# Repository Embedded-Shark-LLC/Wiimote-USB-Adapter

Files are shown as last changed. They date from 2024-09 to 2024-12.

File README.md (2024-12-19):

# Wiimote-USB-Adapter
This is a Wiimote adapter to wirelessly connect remotes for Dolphin or other emulators through a USB-C connection to a computer.

Includes support for sensor bar USB passthrough (power only) or external infrared LEDs to act as a standalone sensor bar.

## Features
- USB-C power/data input
- USB-A port for external sensor bars

## Concept
I wanted a way to connect Wiimotes to a computer without the overhead of third-party Bluetooth adapters.  This uses the OEM Wiimote Bluetooth module, so there is minimal latency and no weird syncing issues.

## Planned Features
- Enclosure with support for integrated IR LEDs to act as a standalone sensor bar

## PCB Renders
|PCB Front|PCB Back|
|---|---|
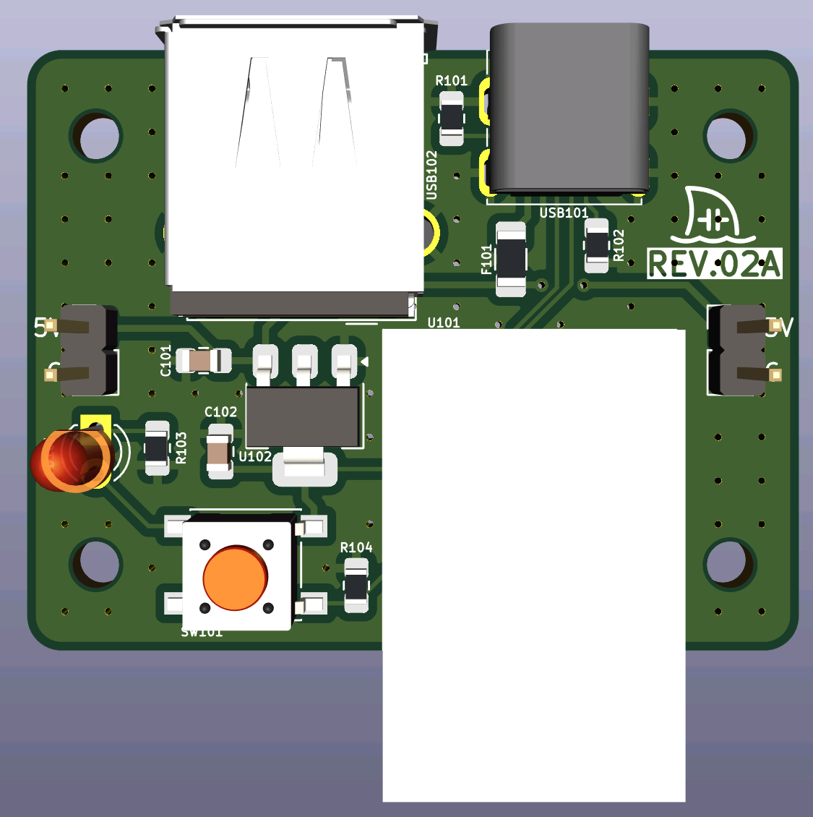
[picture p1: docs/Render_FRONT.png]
PCB front
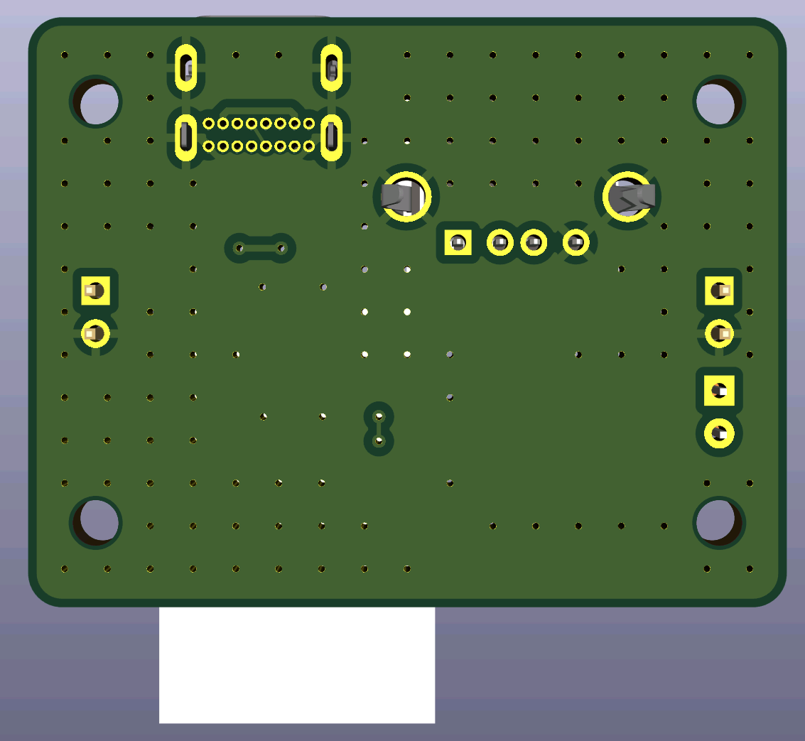
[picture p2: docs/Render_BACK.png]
PCB back
|||

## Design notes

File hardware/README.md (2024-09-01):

# Hardware

## Major components
| Description | Part Number | Manufacturer | Comments |
| --- | --- | --- | --- |
| Bluetooth module | J27H002 | Foxconn | OEM Wiimote BT module |
| Voltage regulator | LM1117MPX-3.3/NOPB | Texas Instruments | 3.3 V, 800 mA |
| USB A port | GSB12121RSKEU | Amphenol | THT, right angle |
| USB C port | GSB1C211110DS1HR | Amphenol | THT, USB 2.0, right angle |
| Sync button | PTS645SM50SMTR92 LFS  | C&K | SMD, vertical |

## Minor components
| Description | Part Number | Manufacturer | Comments |
| --- | --- | --- | --- |
| Resettable fuse | SMD1206B050TF/15 | YAGEO | 500 mA hold, 1 A trip, 15 V max |

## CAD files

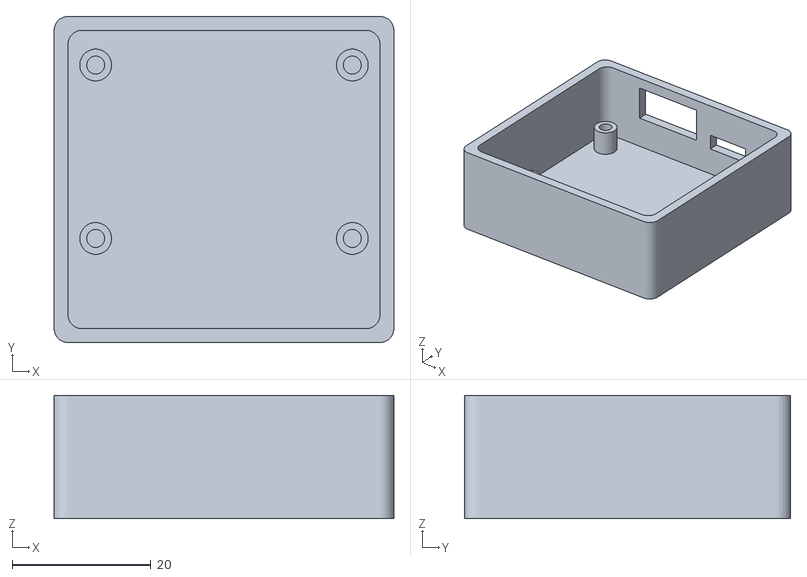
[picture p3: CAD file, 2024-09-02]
enclosure/Wiimote-USB-Adapter-Enclosure-Body.stl
49.0 x 47.0 x 17.8

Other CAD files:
enclosure/Wiimote-USB-Adapter-Enclosure.FCStd

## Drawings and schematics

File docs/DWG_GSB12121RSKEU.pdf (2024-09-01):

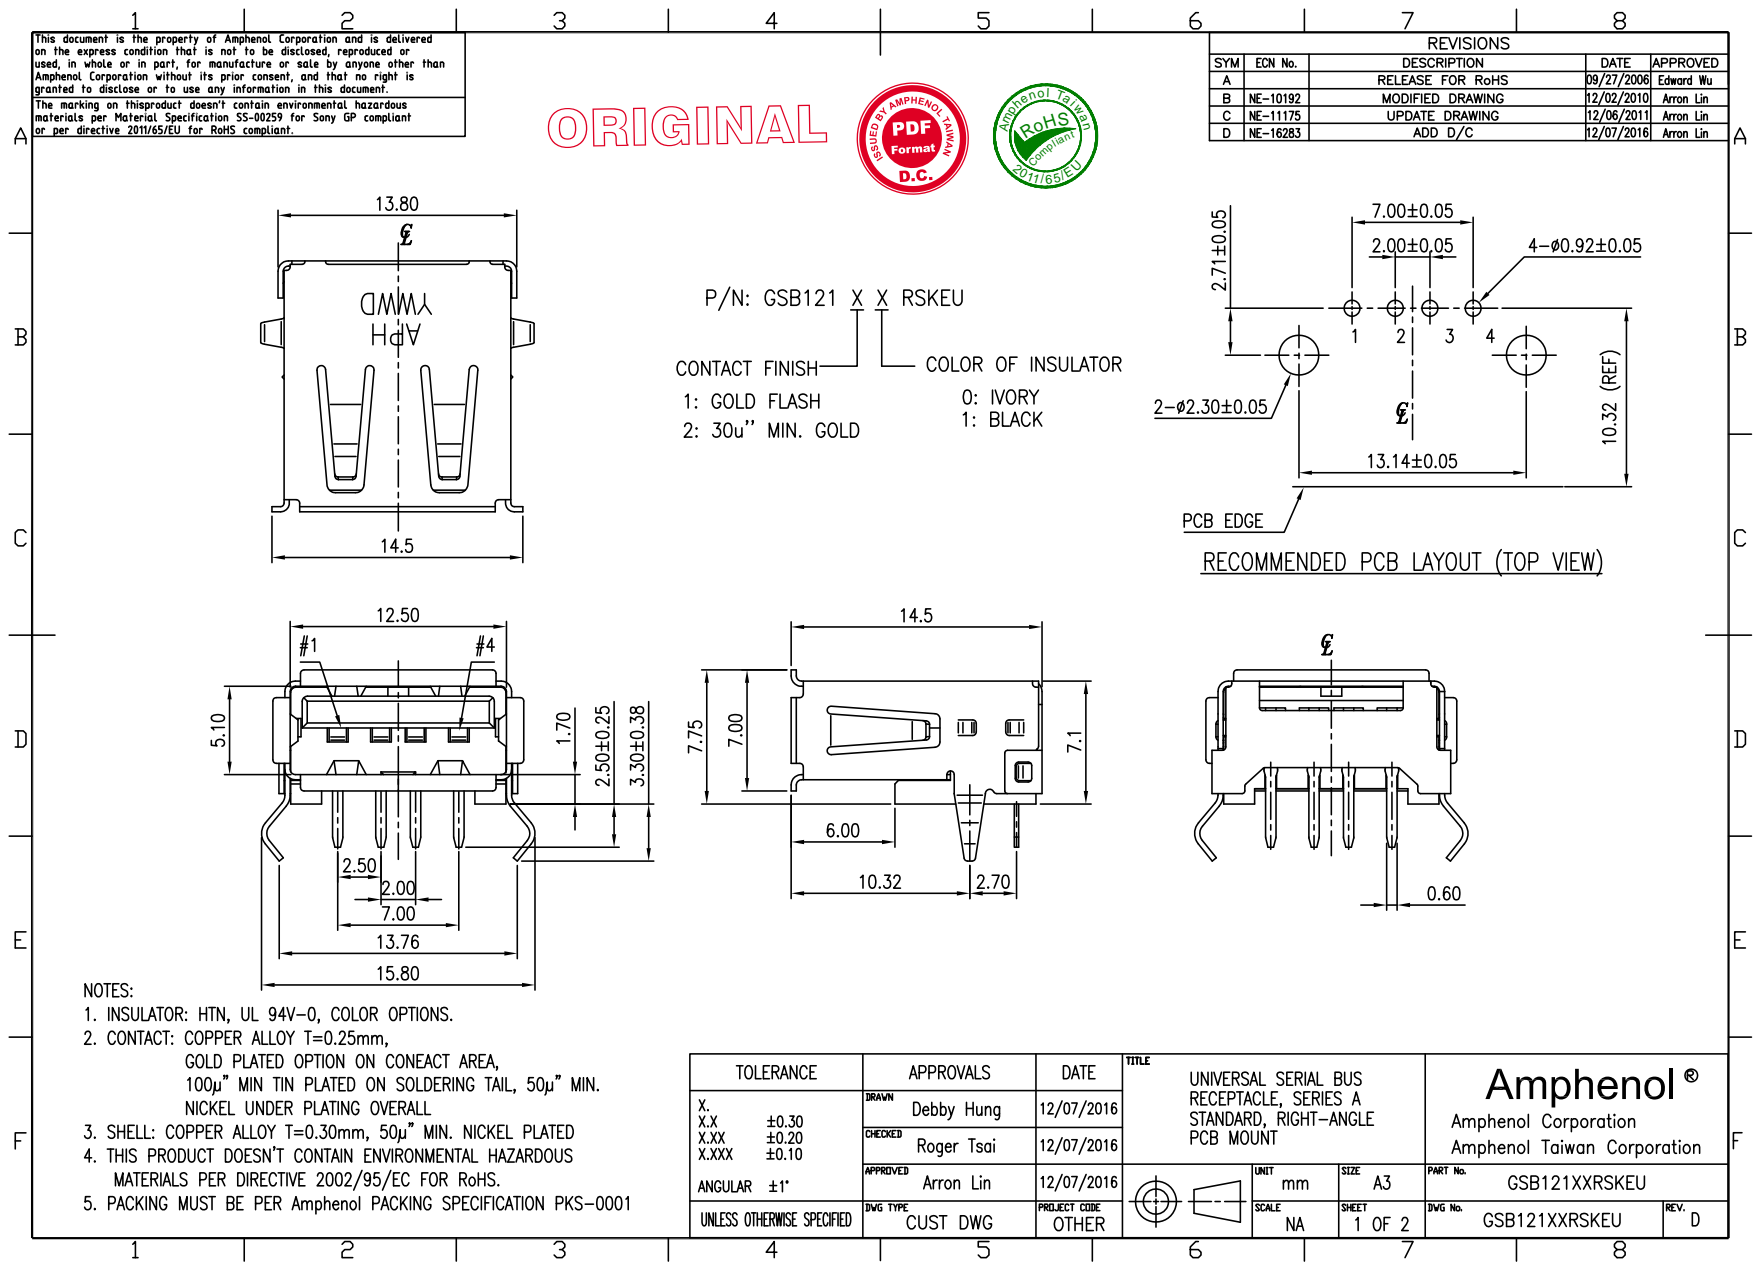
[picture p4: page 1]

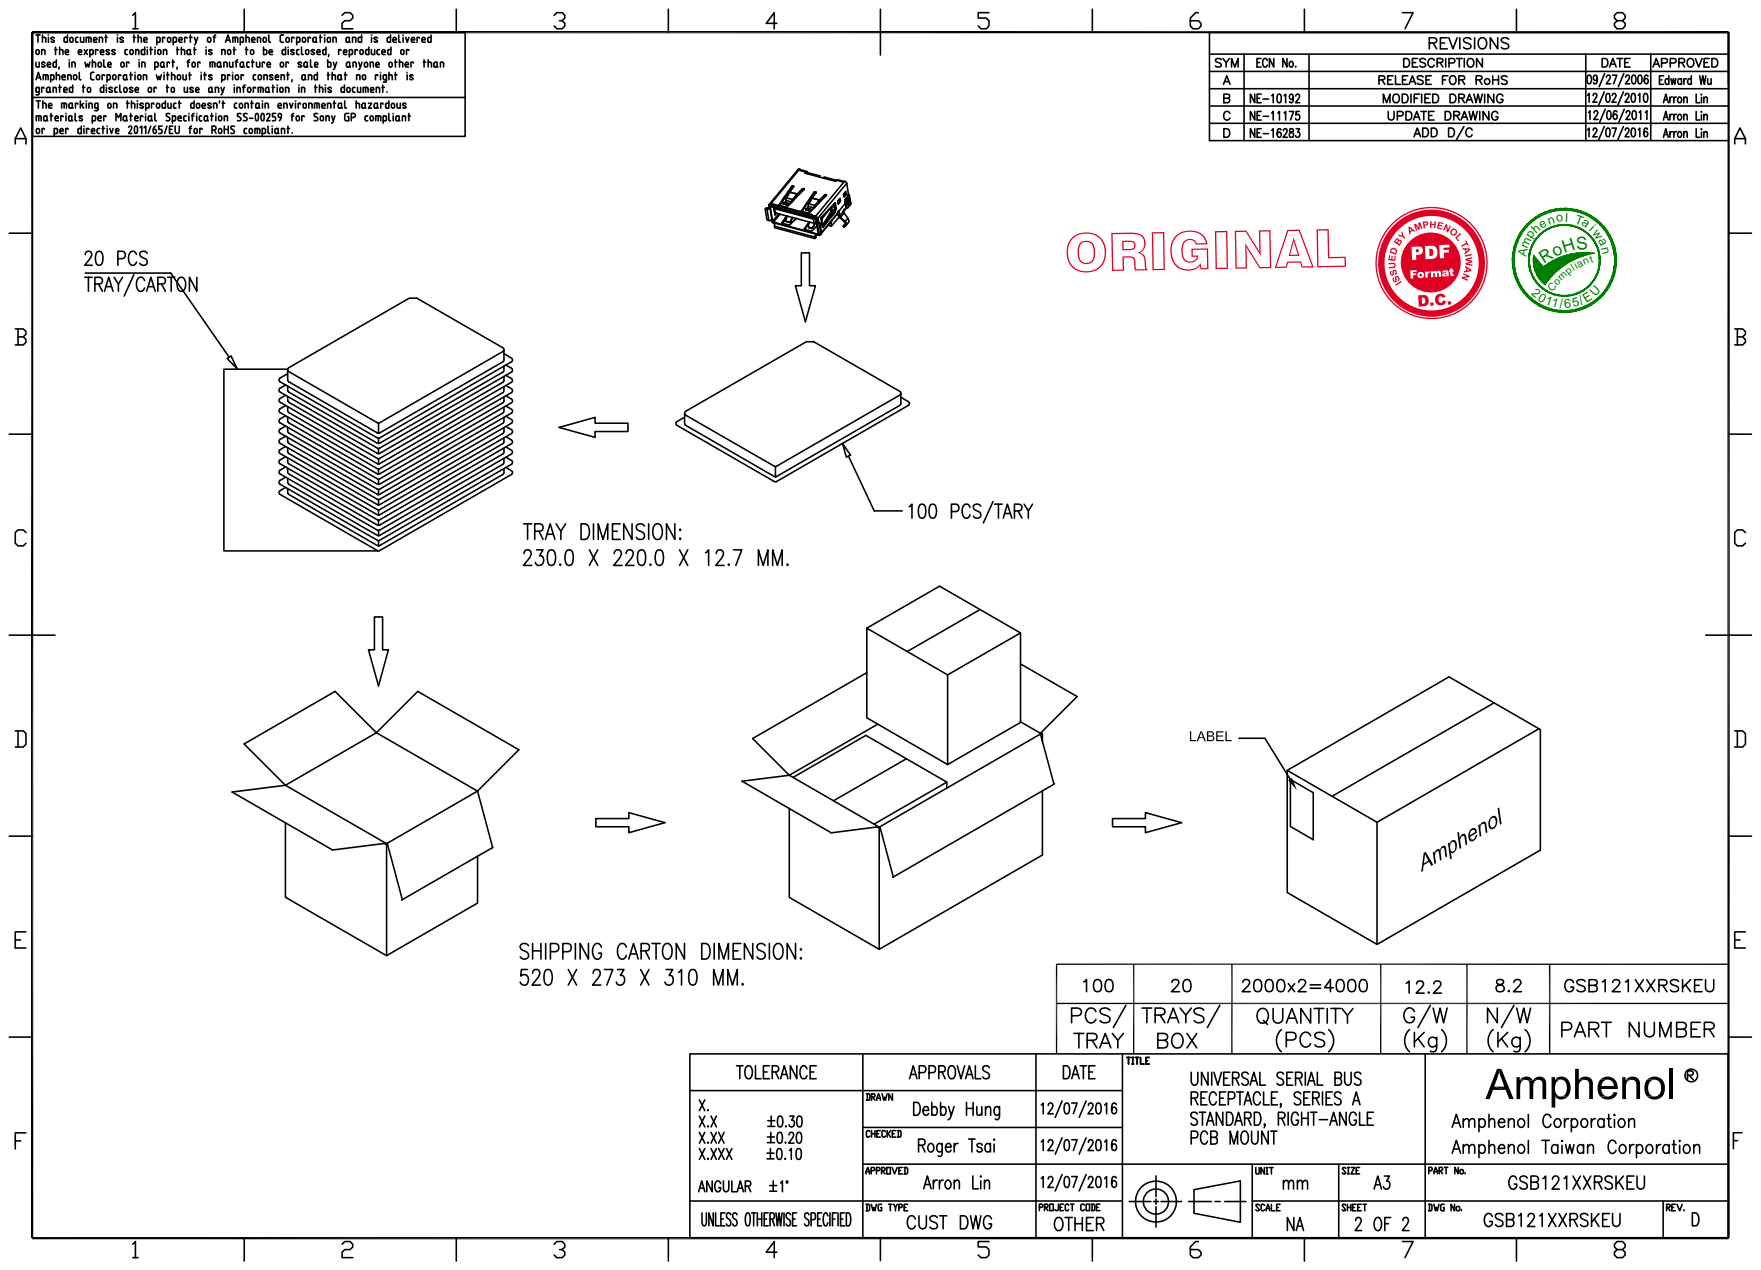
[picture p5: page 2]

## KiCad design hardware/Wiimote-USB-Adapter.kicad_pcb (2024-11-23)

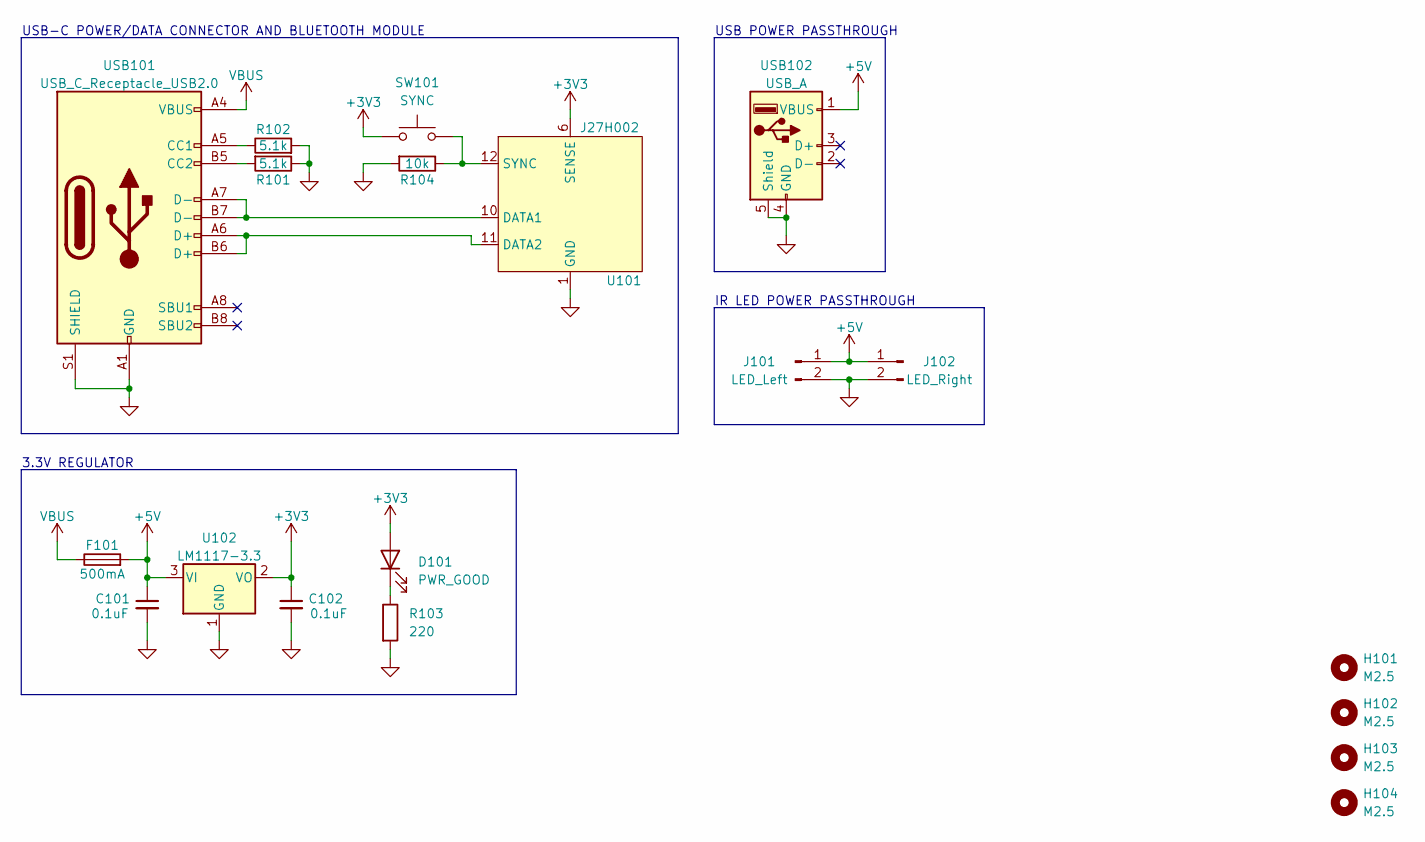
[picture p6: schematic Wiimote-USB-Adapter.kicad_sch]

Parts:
C101, C102: 0.1uF; C_0805_2012Metric_Pad1.18x1.45mm_HandSolder
D101: PWR_GOOD; LED_D3.0mm
F101: 500mA; Fuse_1206_3216Metric_Pad1.42x1.75mm_HandSolder
H101, H102, H103, H104: M2.5; MountingHole_2.7mm_M2.5
J101: LED_Left; PinHeader_1x02_P2.54mm_Vertical
J102: LED_Right; PinHeader_1x02_P2.54mm_Vertical
R101, R102: 5.1k; R_0805_2012Metric_Pad1.20x1.40mm_HandSolder
R103: 220; R_0805_2012Metric_Pad1.20x1.40mm_HandSolder
R104: 10k; R_0805_2012Metric_Pad1.20x1.40mm_HandSolder
SW101: SYNC; SW_SPST_PTS645
U101: J27H002
U102: LM1117-3.3; SOT-223-3_TabPin2
USB101: USB_C_Receptacle_USB2.0; GSB1C211110DS1HR
USB102: USB_A; USB_A_Molex_67643_Horizontal

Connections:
+3V3: C102.1, D101.2 (A), SW101.1, U101.6 (SENSE), U101.7 (SENSE), U101.13 (SENSE), U102.2 (VO)
+5V: C101.1, F101.2, J101.1, J102.1, U102.3 (VI), USB102.1 (VBUS)
GND: C101.2, C102.2, J101.2, J102.2, R101.1, R102.2, R103.2, R104.2, U101.1 (GND), U101.8 (GND), U101.9 (GND), U101.16 (GND), U102.1 (GND), USB101.A1 (GND), USB101.A12 (GND), USB101.B1 (GND), USB101.B12 (GND), USB101.S1 (SHIELD), USB102.4 (GND), USB102.5 (Shield)
unnamed: D101.1 (K), R103.1
unnamed: U101.10 (DATA1), USB101.A7 (D-), USB101.B7 (D-)
unnamed: U101.11 (DATA2), USB101.A6 (D+), USB101.B6 (D+)
unnamed: R104.1, SW101.2, U101.12 (SYNC)
unnamed: R102.1, USB101.A5 (CC1)
unnamed: R101.2, USB101.B5 (CC2)
VBUS: F101.1, USB101.A4 (VBUS), USB101.A9 (VBUS), USB101.B4 (VBUS), USB101.B9 (VBUS)

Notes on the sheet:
USB POWER PASSTHROUGH
3.3V REGULATOR
USB-C POWER/DATA CONNECTOR AND BLUETOOTH MODULE
IR LED POWER PASSTHROUGH

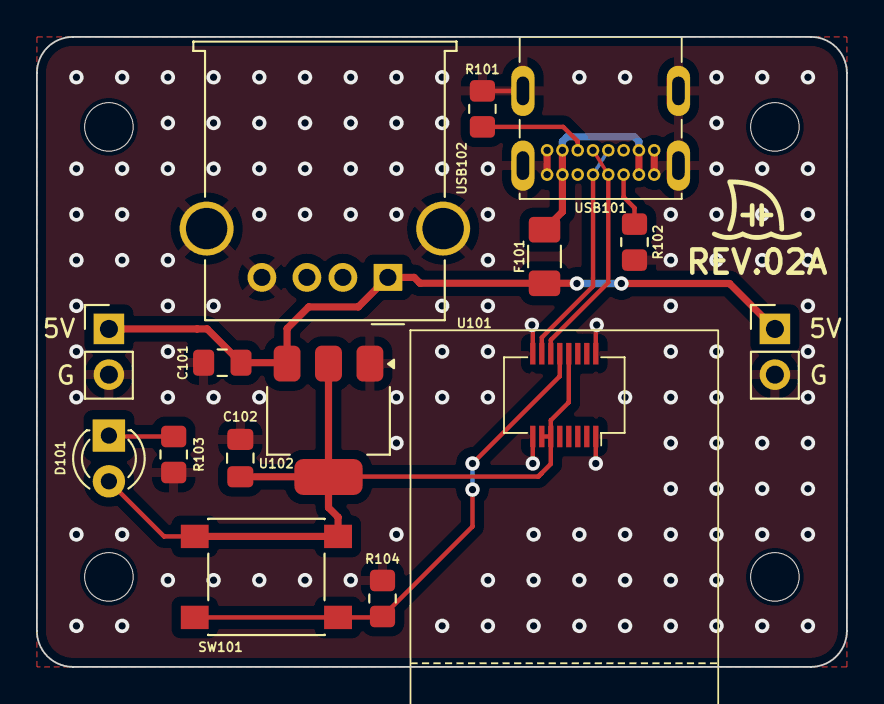
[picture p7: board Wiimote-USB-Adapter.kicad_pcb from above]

Board: 2 copper layers, 45.0 x 35.0 mm, 19 parts (0 on the bottom side), 10 nets.

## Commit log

2022-06-30 Add schematic and begin footprint association
    [Wii Bluetooth Sensor Bar.kicad_pcb, Wii Bluetooth Sensor Bar.kicad_sch]
2022-07-04 Finish footprint assignment and rough PCB layout
    [Wii Bluetooth Sensor Bar.kicad_pcb, Wii Bluetooth Sensor Bar.kicad_sch]
2022-07-06 Finish Rev A PCB
    [Wii Bluetooth Sensor Bar.kicad_pcb, Wii Bluetooth Sensor Bar.kicad_sch]
2022-07-06 Add HTML BOM
2022-07-06 Add 3D models for some components (not accurate)
    [Wii Bluetooth Sensor Bar.kicad_pcb]
2022-07-06 Fix reversed bluetooth module connector
    [Wii Bluetooth Sensor Bar.kicad_pcb]
2022-07-09 Fix incorrect sync button footprint
    [Wii Bluetooth Sensor Bar.kicad_pcb, Wii Bluetooth Sensor Bar.kicad_sch]
2022-07-09 Add PCB label text
    [Wii Bluetooth Sensor Bar.kicad_pcb]
2022-07-27 Fix #1
    [Wii Bluetooth Sensor Bar.kicad_pcb]
2022-07-28 Fix #2
    [Wii Bluetooth Sensor Bar.kicad_sch]
2022-08-02 Add Ben's Universe logo #3
    [Wii Bluetooth Sensor Bar.kicad_pcb]
2022-08-02 Update gitignore for KiCad 6
2022-08-02 KiCad 6 cleanup
2022-08-02 Update versioning
    [Wii Bluetooth Sensor Bar.kicad_pcb]
2022-08-02 Delete Hardware/Wii Bluetooth Sensor Bar-backups directory
    KiCad 6 cleanup
2022-08-03 Create enclosure model (not finished)
    [Enclosure.FCStd]
2022-08-03 First draft of enclosure base (added port holes)
    [Enclosure-Body.stl, Enclosure.FCStd]
2022-08-04 Fix missing threaded insert hole, antenna overhang
    [Enclosure-Body.stl, Enclosure.FCStd]
2022-08-04 Increase wall thickness and add supports
    [Enclosure.FCStd]
2022-08-04 Remove STLs folder
    [Enclosure-Body.stl]
2022-08-04 Add enclosure lid
    [Enclosure.FCStd]
2022-08-04 Add button extension
    [Enclosure.FCStd]
2022-08-04 Add STL files
    [Enclosure-Base.stl, Enclosure-Button.stl, Enclosure-Lid.stl]
2022-08-04 Fix physical antenna interference
    [Enclosure-Base.stl, Enclosure.FCStd]
2022-08-04 Fix port hole sizes and button extension length
    [Enclosure-Base.stl, Enclosure-Button.stl, Enclosure-Lid.stl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]
2022-08-05 Increase USB-C port hole
    [Enclosure-Base.stl, Enclosure-Lid.stl, Enclosure.FCStd]
2022-08-05 Enlarge USB-C port
    [Enclosure-Base.stl, Enclosure.FCStd]
2022-08-05 Add 3D printing suggestions
2022-08-05 Raise USB-A port hole
    [Enclosure-Base.stl, Enclosure.FCStd]
2022-08-05 Update 3D printing instructions
2022-08-06 Make button extension longer
    [Enclosure-Button.stl, Enclosure.FCStd]
2022-08-06 Make countersunk screw hole deeper
    [Enclosure-Lid.stl, Enclosure.FCStd]
2022-08-18 Fix bad pulldown resistor
    [Wii Bluetooth Sensor Bar.kicad_pcb, Wii Bluetooth Sensor Bar.kicad_sch]
2022-08-18 Update new sync button placement
    [Enclosure-Lid.stl, Enclosure.FCStd]
2024-09-01 Add submodule and clean up repository
    [Enclosure-Base.stl, Enclosure-Button.stl, Enclosure-Lid.stl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]
2024-09-01 Update schematic/PCB
    [Wii-Bluetooth-Sensor-Bar.kicad_pcb, Wii-Bluetooth-Sensor-Bar.kicad_sch]
2024-09-01 Remove old enclosure files
    [Enclosure-Base.stl, Enclosure-Button.stl, Enclosure-Lid.stl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]
2024-09-01 Add 3D model for J27H002 and drawings
    [Wii-Bluetooth-Sensor-Bar.kicad_pcb]
2024-09-01 Change project name
    [Wiimote-USB-Adapter.kicad_pcb, Wiimote-USB-Adapter.kicad_sch]
2024-09-02 Add more dimensions
    [Wiimote-USB-Adapter.kicad_pcb]
2024-09-02 First draft of new enclosure body
    [Wiimote-USB-Adapter-Enclosure-Body.stl, Wiimote-USB-Adapter-Enclosure.FCStd]
2024-09-14 Clean up silkscreen and vias
    [Wiimote-USB-Adapter.kicad_pcb]
2024-11-23 Remove PCB markings
    [Wiimote-USB-Adapter.kicad_pcb]
